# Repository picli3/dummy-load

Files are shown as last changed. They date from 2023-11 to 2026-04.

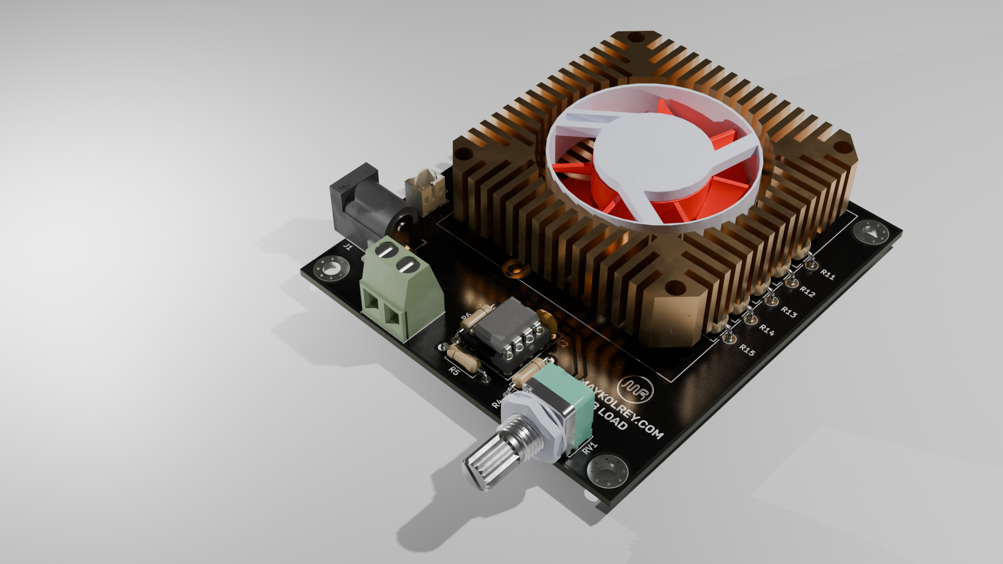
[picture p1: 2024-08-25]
render.png

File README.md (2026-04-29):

# dummy-load

Carga electrónica o dummy load basada en **LM358** y MOSFET, pensada para probar fuentes de alimentación y convertidores bajo condiciones controladas.

## Propósito del proyecto
Este diseño permite aplicar una carga artificial a una fuente o etapa DC para evaluar regulación, calentamiento, respuesta y comportamiento general sin depender de una carga real fija.

## Qué incluye
- esquemático de la carga electrónica
- PCB en KiCad
- base práctica para laboratorio, pruebas y validación de fuentes

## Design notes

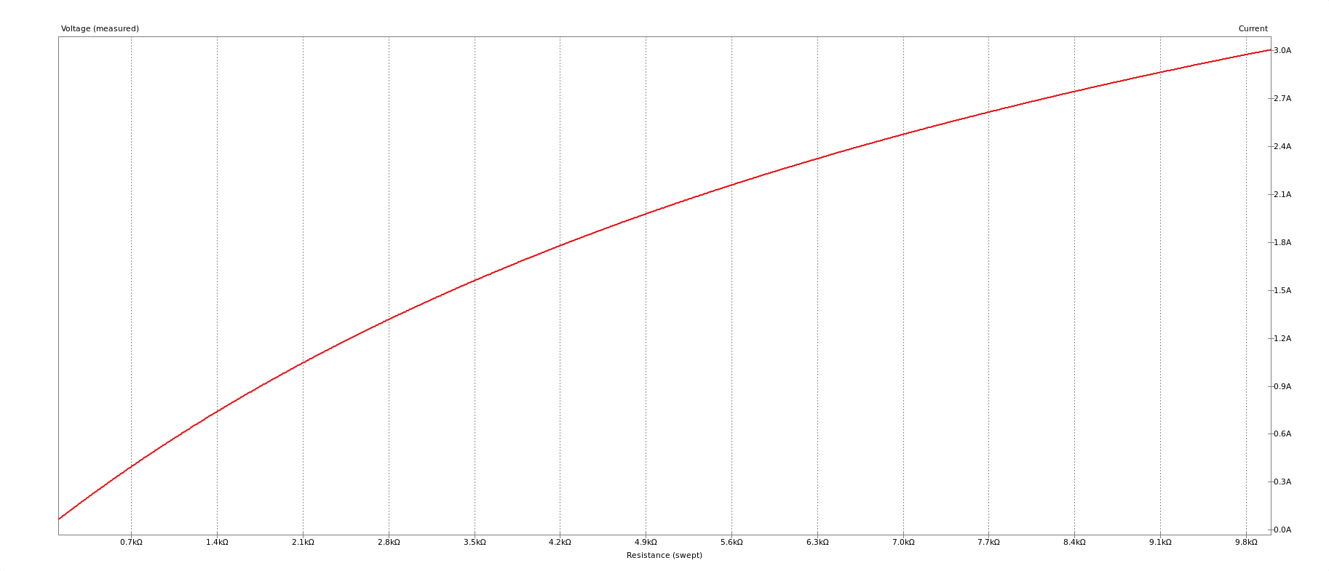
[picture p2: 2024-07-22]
graph_LM358.png

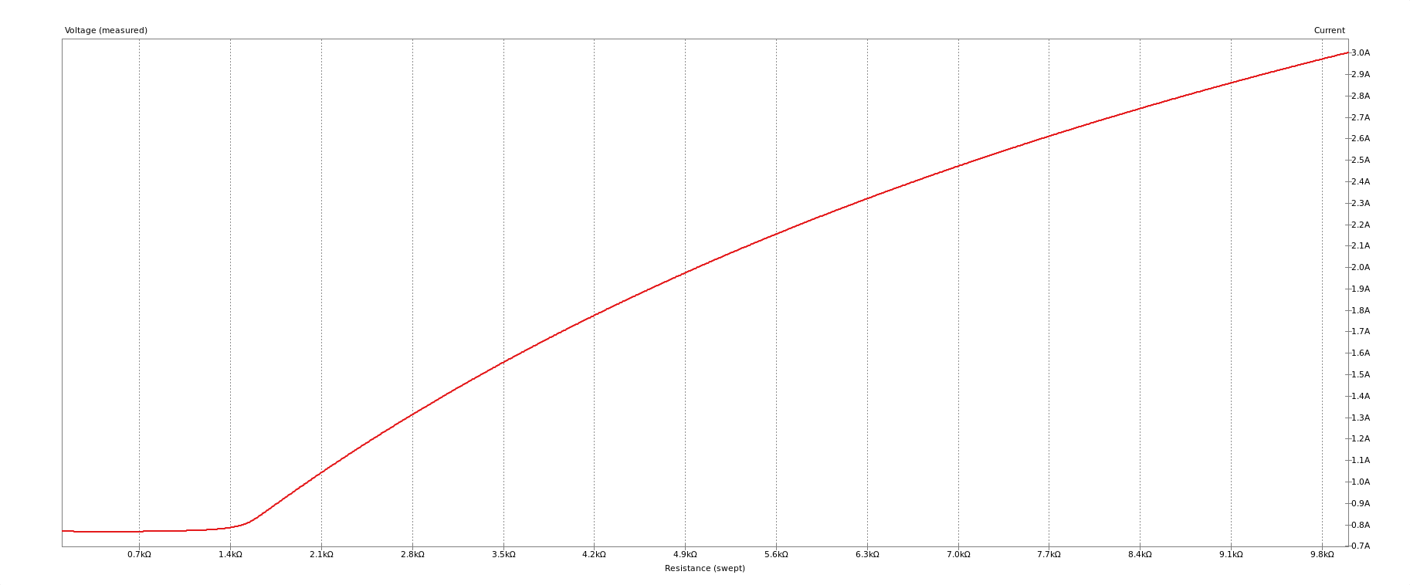
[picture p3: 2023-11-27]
graph.png

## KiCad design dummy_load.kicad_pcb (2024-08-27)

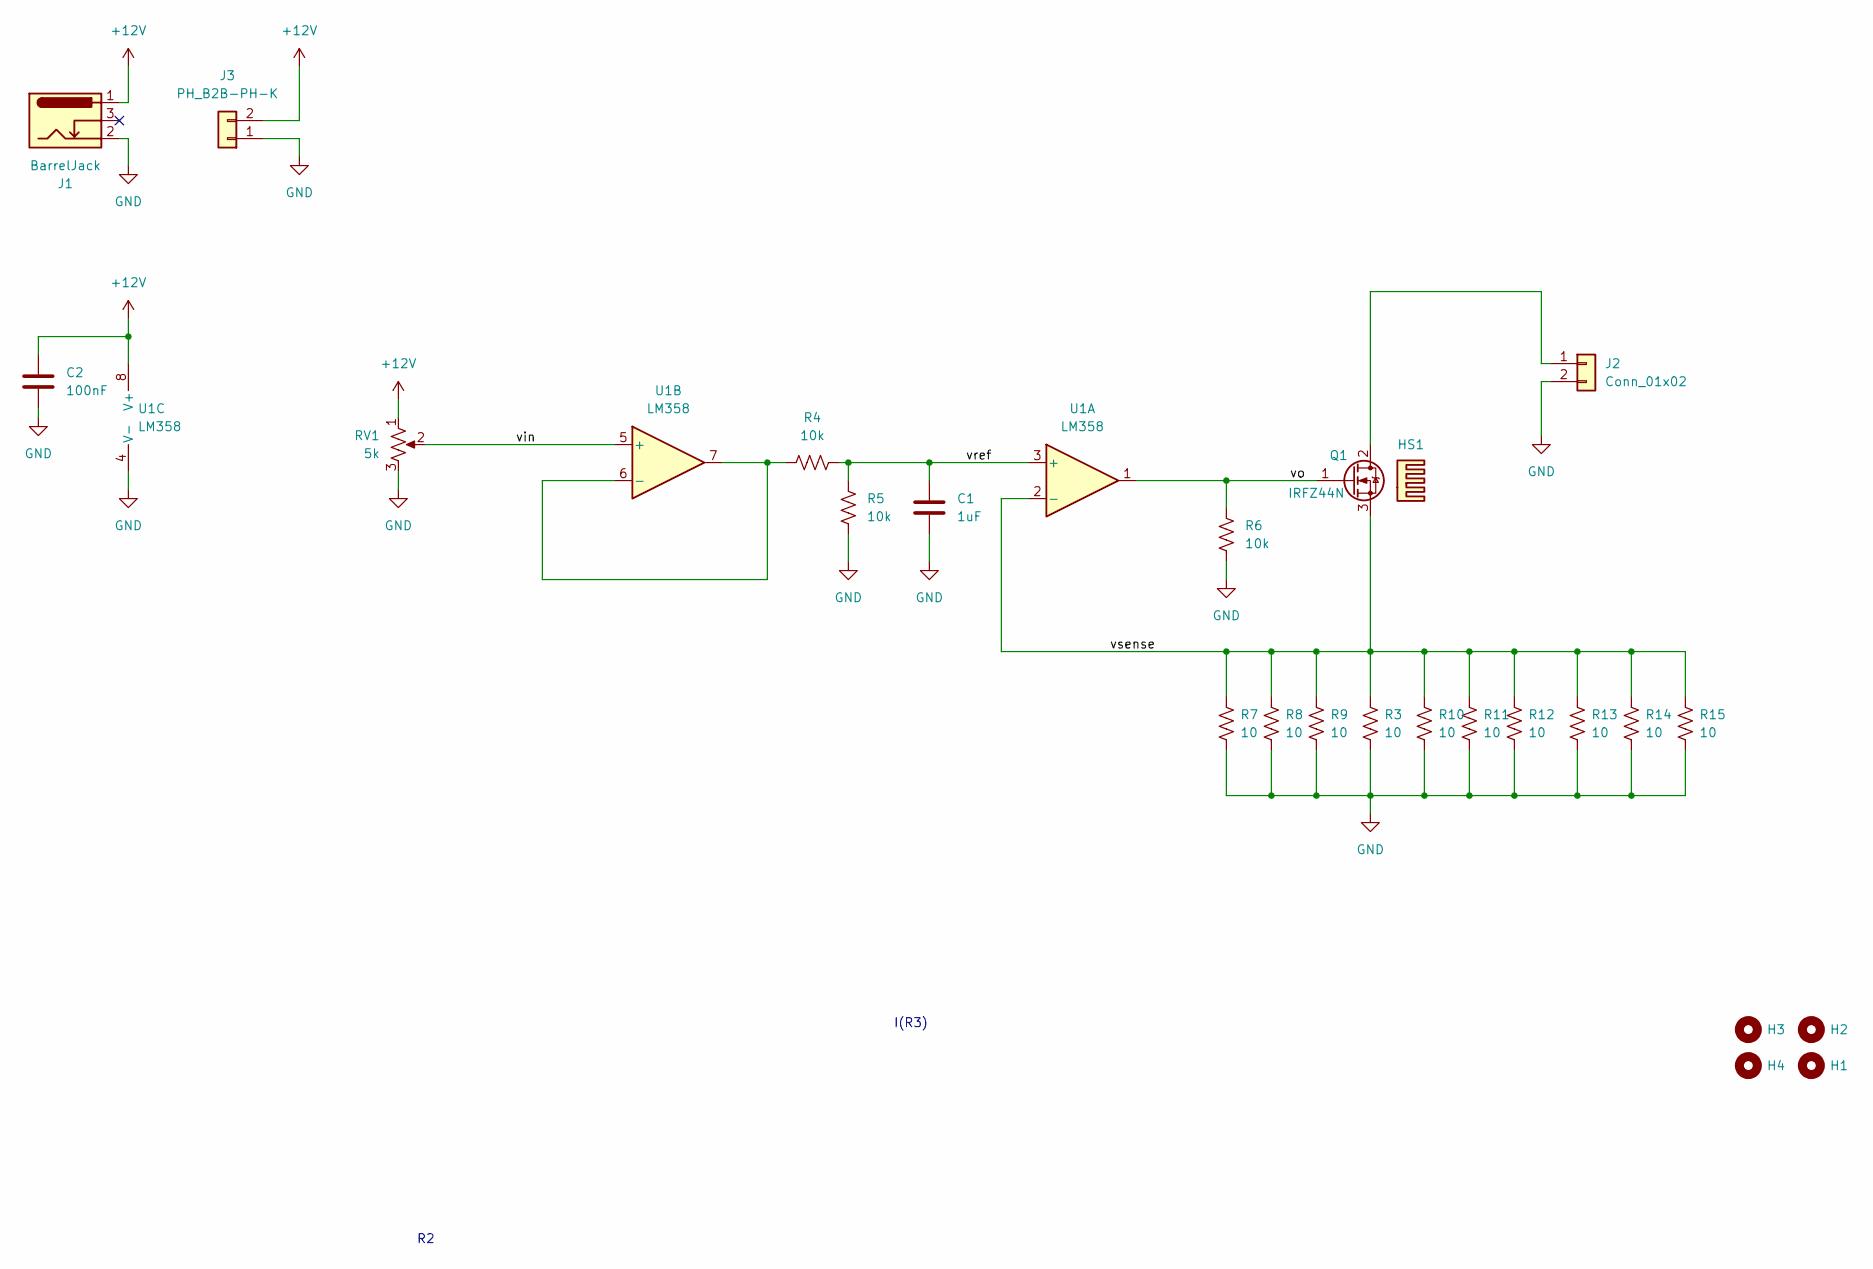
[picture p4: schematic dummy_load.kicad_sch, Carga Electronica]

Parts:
C1: 1uF; C_Disc_D5.0mm_W2.5mm_P5.00mm
C2: 100nF; C_Disc_D5.0mm_W2.5mm_P2.50mm
H1, H2, H3, H4: MountingHole; MountingHole_3.2mm_M3_Pad_Via
HS1: Heatsink; disipador_VGA
J1: BarrelJack; BarrelJack_Horizontal
J2: Conn_01x02; TerminalBlock_Phoenix_MKDS-1,5-2-5.08_1x02_P5.08mm_Horizont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
J3: PH_B2B-PH-K; JST_PH_B2B-PH-K_1x02_P2.00mm_Vertical
Q1: IRFZ44N; TO-220-3_Horizontal_TabUp
R3, R7, R8, R9, R10, R11, R12, R13, R14, R15: 10; R_Axial_DIN0414_L11.9mm_D4.5mm_P15.24mm_Horizontal
R4, R5, R6: 10k; R_Axial_DIN0207_L6.3mm_D2.5mm_P10.16mm_Horizontal
RV1: 5k; Potentiometer_Alps_RK09Y11_Single_Horizontal
U1: LM358; DIP-8_W7.62mm_Socket

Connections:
+12V: C2.1, J1.1, J3.2, RV1.1, U1.8 (V+)
/vin: RV1.2, U1.5 (+)
/vo: Q1.1 (G), R6.2, U1.1
/vref: C1.1, R4.1, R5.1, U1.3 (+)
/vsense: Q1.3 (S), R3.1, R7.1, R8.1, R9.1, R10.1, R11.1, R12.1, R13.1, R14.1, R15.1, U1.2 (-)
GND: C1.2, C2.2, J1.2, J2.2, J3.1, R3.2, R5.2, R6.1, R7.2, R8.2, R9.2, R10.2, R11.2, R12.2, R13.2, R14.2, R15.2, RV1.3, U1.4 (V-)
unnamed: J2.1, Q1.2 (D)
unnamed: R4.2, U1.6 (-), U1.7

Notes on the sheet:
I(R3)

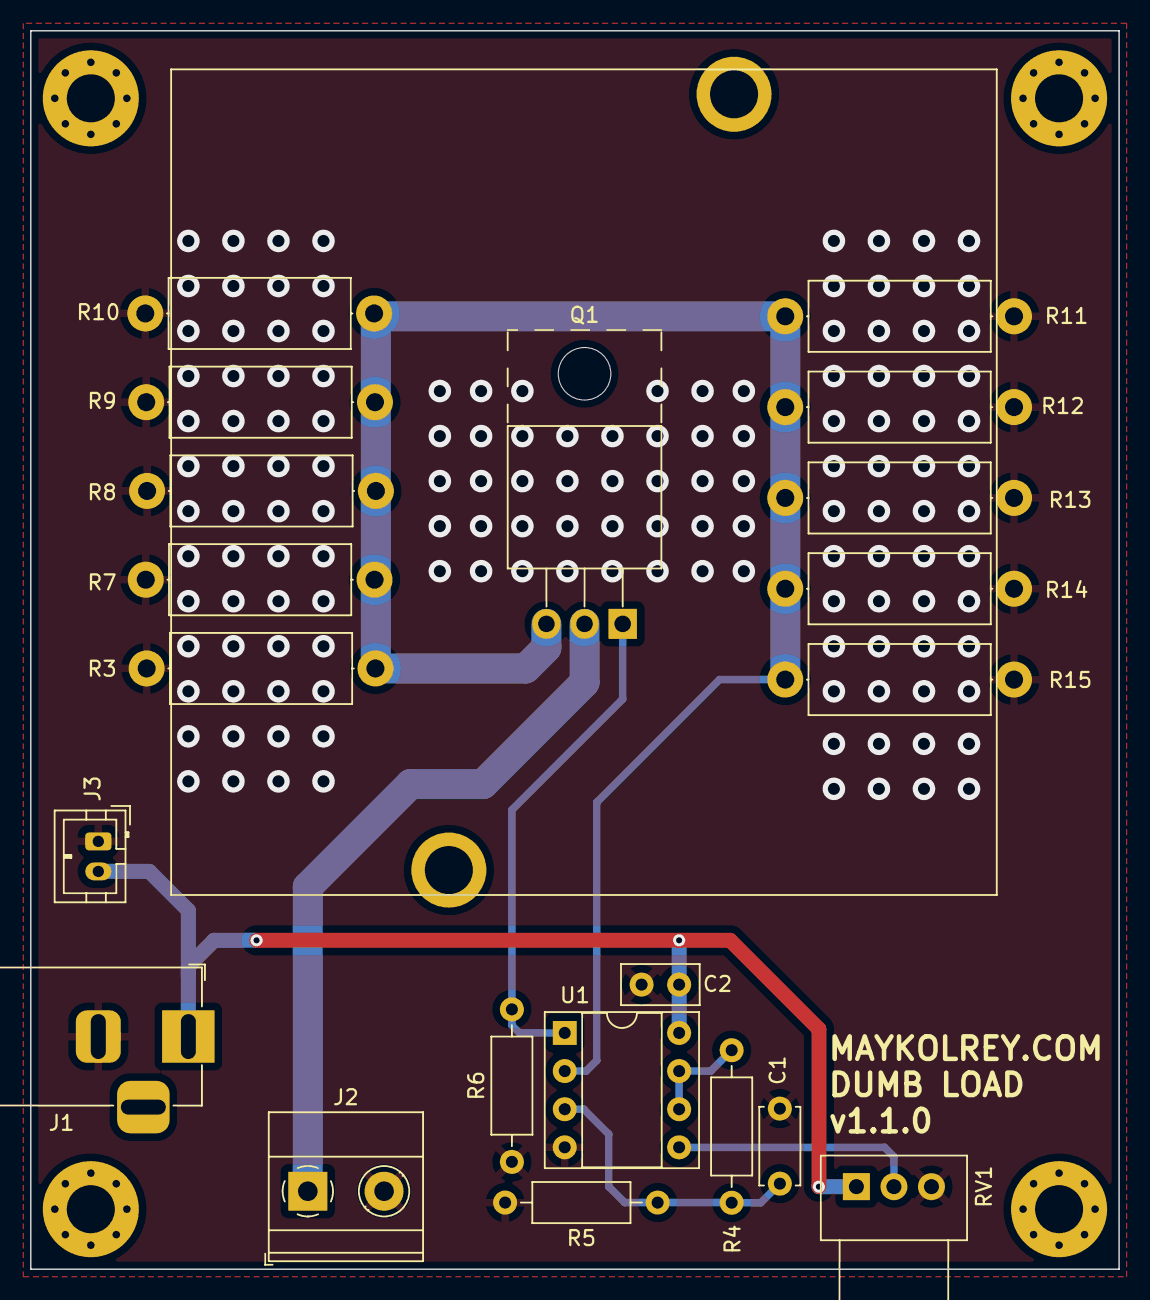
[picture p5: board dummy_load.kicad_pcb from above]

Board: 2 copper layers, 72.5 x 82.5 mm, 26 parts (0 on the bottom side), 8 nets.

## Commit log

2023-11-27 dummy load TL082
    [dummy_load.kicad_pcb, dummy_load.kicad_sch]
2023-11-29 version con LM358 (SIMULACION)
    [dummy_load.kicad_pcb, dummy_load.kicad_sch]
2024-07-22 Completada la version 1
    [dummy_load.kicad_pcb, dummy_load.kicad_sch]
2024-08-24 corrigiendo footprint del disipador de calor
    [dummy_load.kicad_pcb, dummy_load.kicad_sch]
2024-08-25 creando archivos de fabricación
    [dummy_load.kicad_pcb, dummy_load.kicad_sch]
2024-08-27 corrigiendo el conector jack-DC invertido
    [dummy_load.kicad_pcb, dummy_load.kicad_sch]
